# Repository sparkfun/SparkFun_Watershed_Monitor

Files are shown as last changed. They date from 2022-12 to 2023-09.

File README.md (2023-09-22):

# SparkFun Watershed Monitor

Repository Contents
-------------------

* **/Documentation** - Data sheets, additional product information
* **/Hardware** - Eagle design files (.brd, .sch)
* **/Production** - Production panel files (.brd)

License Information
-------------------

This product is _**open source**_! 

Please review the LICENSE.md file for license information. 

If you have any questions or concerns on licensing, please contact technical support on our [SparkFun forums](https://forum.sparkfun.com/viewforum.php?f=152).

Distributed as-is; no warranty is given.

- Your friends at SparkFun.

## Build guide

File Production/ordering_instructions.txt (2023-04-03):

panel size, 142x237mm
PCB thickness, 1.6mm
number of layers, 2
soldermask color, Red
silkscreen color, White
oz copper, 1oz
finish, HASL lead free
stencils, top
pcs per panel, 6
min trace width, 0.2286mm / 0.0090in
min drill size, 0.3048mm / 0.0120in

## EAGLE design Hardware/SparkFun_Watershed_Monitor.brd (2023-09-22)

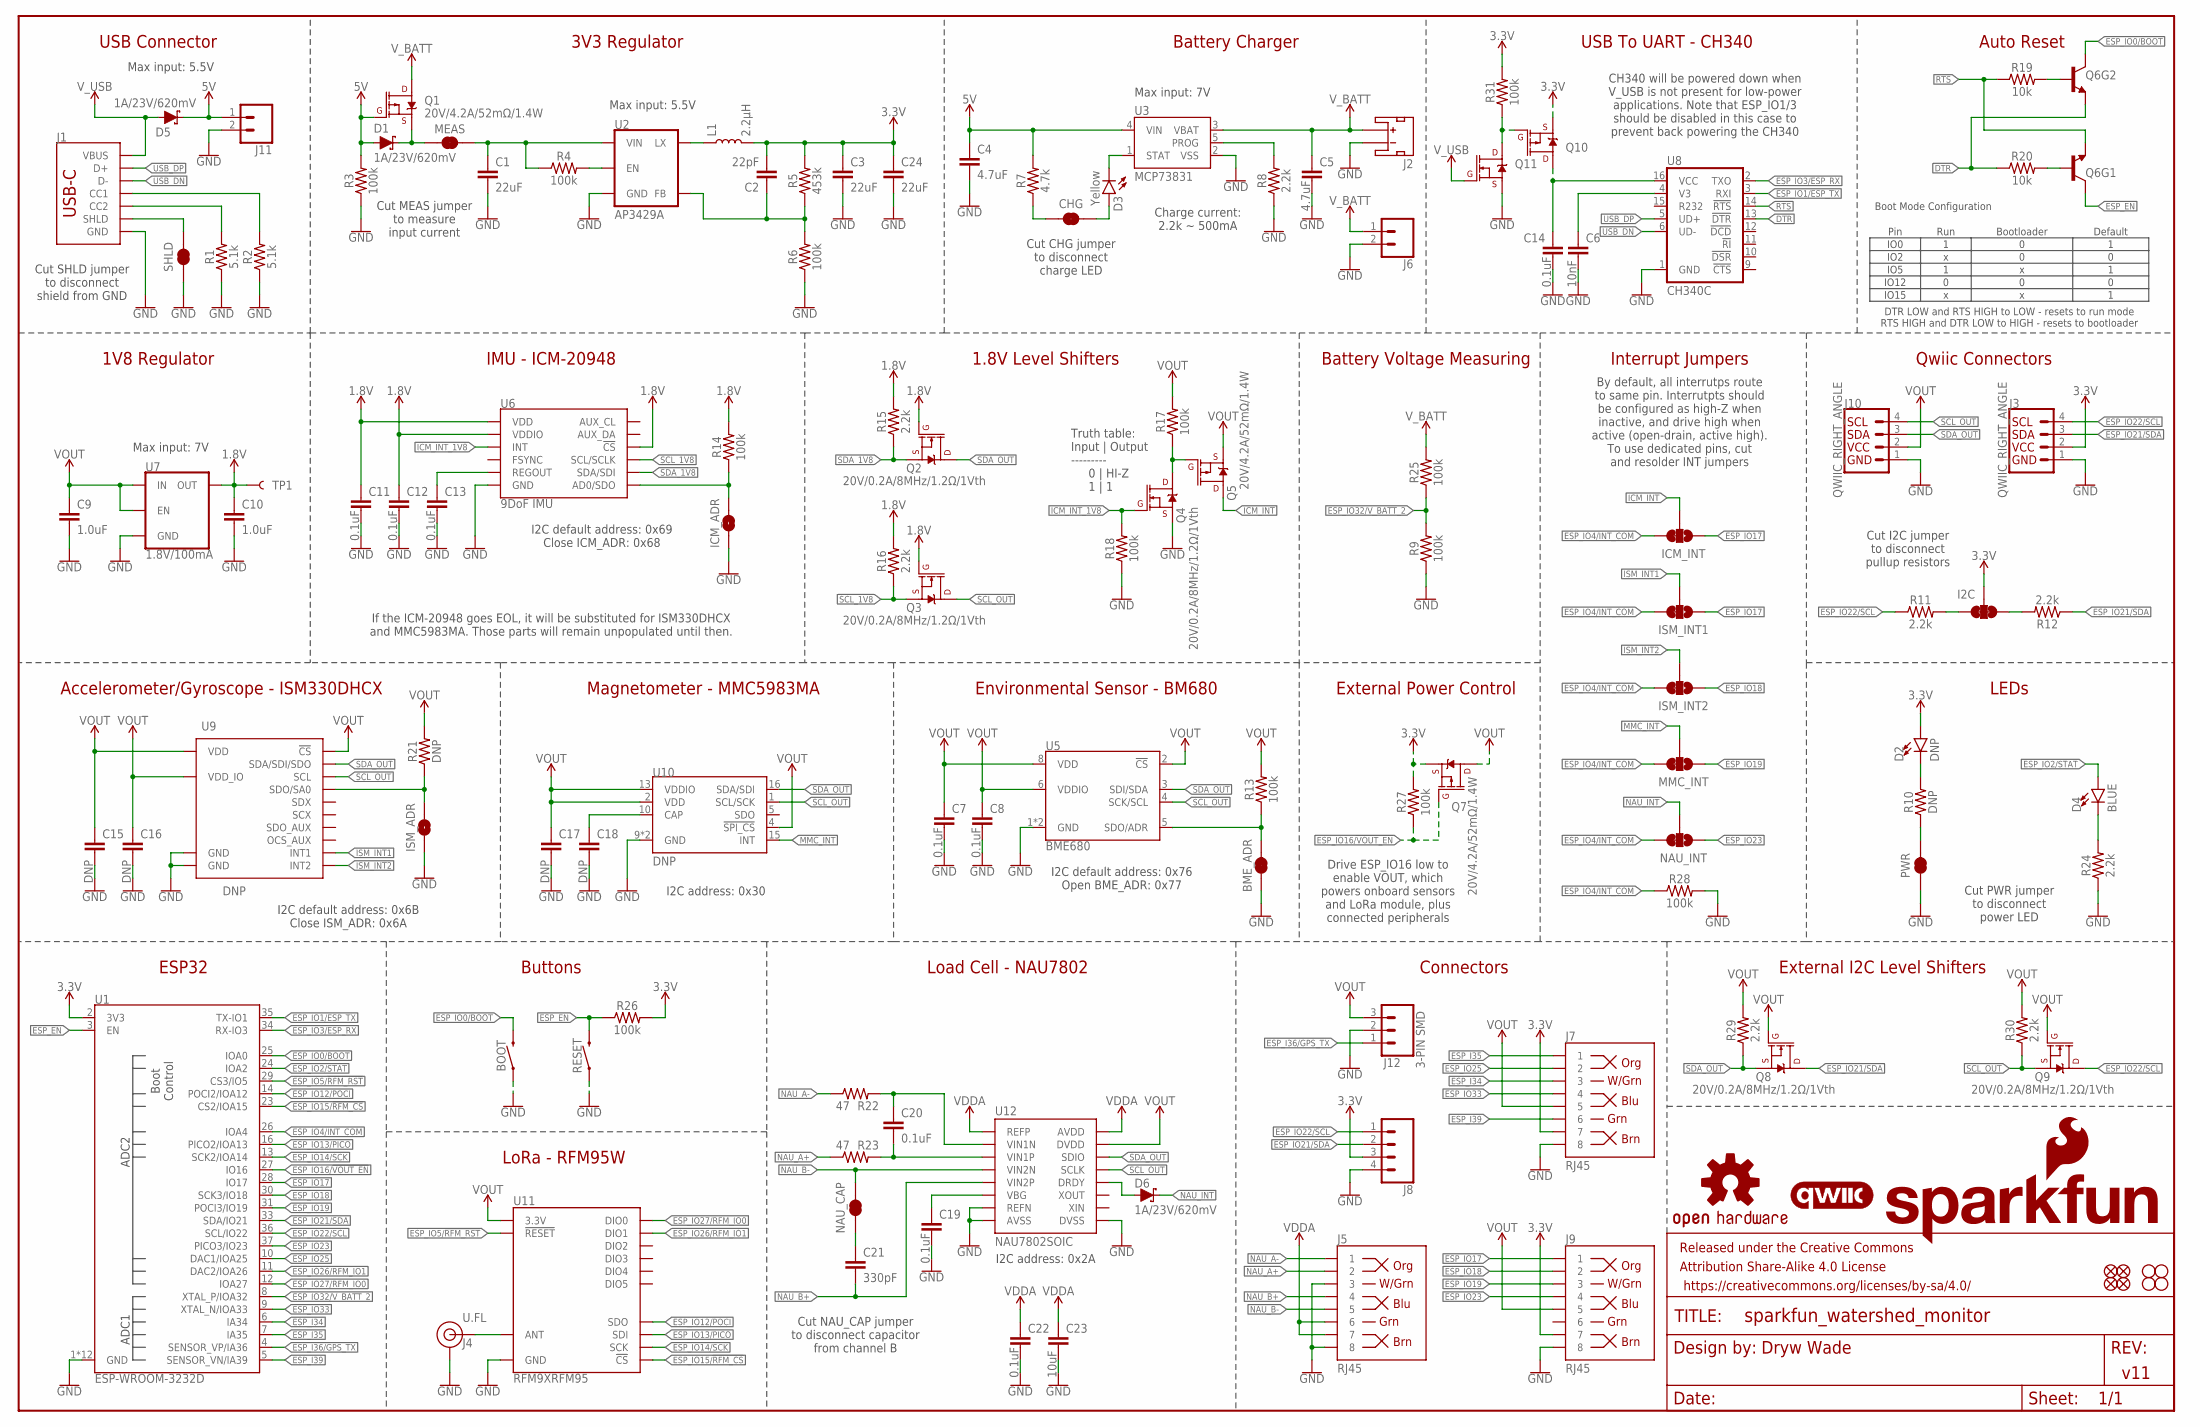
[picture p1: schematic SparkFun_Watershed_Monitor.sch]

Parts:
BME_ADR: JUMPER-SMT_2_NC_TRACE_SILK; SMT-JUMPER_2_NC_TRACE_SILK
BOOT: MOMENTARY-SWITCH-SPST-SMD-4.6X2.8MM; TACTILE_SWITCH_SMD_4.6X2.8MM
C1, C3, C24: 22uF; 0805
C2: 22pF; 0603
C4, C5: 4.7uF; 0603
C6: 10nF; 0603
C7, C8, C11, C12, C13, C14, C19, C20, C22: 0.1uF; 0603
C9, C10: 1.0uF; 0603
C15, C16, C17, C18: DNP; 0603
C21: 330pF; 0603
C23: 10uF; 0603
CHG: JUMPER-SMT_2_NC_TRACE_SILK; SMT-JUMPER_2_NC_TRACE_SILK
D1, D5, D6: 1A/23V/620mV; SOD-323
D2: DNP; LED-0603
D3: Yellow; LED-0603
D4: BLUE; LED-0603
FD1, FD2, FD3, FD4: FIDUCIAL1X2; FIDUCIAL-1X2
FRAME1: FRAME-LEDGER; CREATIVE_COMMONS
H1, H2, H3, H4: STAND-OFF
I2C: JUMPER-SMT_3_2-NC_TRACE_SILK; SMT-JUMPER_3_2-NC_TRACE_SILK
ICM_ADR: JUMPER-SMT_2_NO_SILK; SMT-JUMPER_2_NO_SILK
ICM_INT: JUMPER-SMT_3_1-NC_TRACE_SILK; SMT-JUMPER_3_1-NC_TRACE_SILK
ISM_ADR: JUMPER-SMT_2_NO_SILK; SMT-JUMPER_2_NO_SILK
ISM_INT1, ISM_INT2: JUMPER-SMT_3_1-NC_TRACE_SILK; SMT-JUMPER_3_1-NC_TRACE_SILK
J1: USB_C_2-LAYER_PADS; USB-C-16P-2LAYER-PADS
J2: JST_2MM_MALE; JST-2-SMD
J3, J10: QWIIC_RIGHT_ANGLE; JST04_1MM_RA
J4: U.FL
J5, J7, J9: RJ45; RJ45-8
J6, J11: CONN_021X02_NO_SILK; 1X02_NO_SILK
J8: CONN_041X04_NO_SILK_NO_POP; 1X04_NO_SILK
J12: 3-PIN SMD; JST-3-SMD
L1: 2.2μH; INDUCTOR_4X4MM
LOGO1: SFE_LOGO_NAME_FLAME.1_INCH; SFE_LOGO_NAME_FLAME_.1
LOGO2: OSHW-LOGOS; OSHW-LOGO-S
LOGO3: QWIIC_LOGO_4MM; QWIIC_4MM
MEAS: JUMPER-COMBO_2_NC_TRACE; COMBO-JUMPER_2_NC_TRACE
MMC_INT: JUMPER-SMT_3_1-NC_TRACE_SILK; SMT-JUMPER_3_1-NC_TRACE_SILK
NAU_CAP: JUMPER-SMT_2_NC_TRACE_SILK; SMT-JUMPER_2_NC_TRACE_SILK
NAU_INT: JUMPER-SMT_3_1-NC_TRACE_SILK; SMT-JUMPER_3_1-NC_TRACE_SILK
PWR: JUMPER-SMT_2_NC_TRACE_SILK; SMT-JUMPER_2_NC_TRACE_SILK
Q1, Q5, Q7, Q10: 20V/4.2A/52mΩ/1.4W; SOT23-3
Q2, Q3, Q4, Q8, Q9, Q11: 20V/0.2A/8MHz/1.2Ω/1Vth; SOT-416FL
Q6: TRANS_NPN_DUAL-MBT3904DW1T1; SC70-6
R1, R2: 5.1k; 0603
R3, R4, R6, R9, R13, R14, R17, R18, R25, R26, R27, R28, R31: 100k; 0603
R5: 453k; 0603
R7: 4.7k; 0603
R8, R11, R12, R15, R16, R24, R29, R30: 2.2k; 0603
R10, R21: DNP; 0603
R19, R20: 10k; 0603
R22, R23: 47; 0603
RESET: MOMENTARY-SWITCH-SPST-SMD-4.6X2.8MM; TACTILE_SWITCH_SMD_4.6X2.8MM
SHLD: JUMPER-SMT_2_NC_TRACE_SILK; SMT-JUMPER_2_NC_TRACE_SILK
TP1: TEST-POINT3X4; PAD.03X.04
U1: ESP-WROOM-3232D; ESP-WROOM-32D
U2: AP3429A; SOT23-5
U3: MCP73831; SOT23-5
U5: BME680; LGA3.0X3.0
U6: 9DoF IMU; QFN24-3X3-ICM-20948
U7: 1.8V/100mA; SC70
U8: CH340C; SO016
U9: DNP; LGA-14L
U10: DNP; LGA-16-3X3MM-4X4PINS
U11: RFM9XRFM95; RFM95
U12: NAU7802SOIC; SO16

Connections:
1.8V: C10.1, C11.1, C12.1, Q2.1 (G), Q3.1 (G), R14.2, R15.2, R16.2, TP1.1, U6.8 (VDDIO), U6.13 (VDD), U6.22 (!CS), U7.5 (OUT)
3.3V: C2.2, C3.1, C24.1, D2.A, I2C.2, J3.2, J7.7, J8.3, J9.7, L1.P$2 (2), Q7.2 (S), Q10.2 (S), R5.2, R26.2, R27.2, R31.2, U1.2 (3V3)
3V3_EN: R4.2, U2.1 (EN)
5V: C4.1, D1.A, D5.C, J11.1, Q1.1 (G), R3.2, R7.2, U3.4 (VIN)
DTR: Q6.1 (E), R20.1, U8.13 (!DTR)
ESP_EN: Q6.3 (C), R26.1, RESET.3 (2), RESET.4 (2), U1.3 (EN)
ESP_I34: J7.3, U1.6 (IA34)
ESP_I35: J7.1, U1.7 (IA35)
ESP_I36/GPS_TX: J12.1 (3), U1.4 (SENSOR_VP/IA36)
ESP_I39: J7.6, U1.5 (SENSOR_VN/IA39)
ESP_IO0/BOOT: BOOT.3 (2), BOOT.4 (2), Q6.6 (C), U1.25 (IOA0)
ESP_IO1/ESP_TX: U1.35 (TX-IO1), U8.3 (RXI)
ESP_IO2/STAT: D4.A, U1.24 (IOA2)
ESP_IO3/ESP_RX: U1.34 (RX-IO3), U8.2 (TXO)
ESP_IO4/INT_COM: ICM_INT.3, ISM_INT1.3, ISM_INT2.3, MMC_INT.3, NAU_INT.3, R28.1, U1.26 (IOA4)
ESP_IO5/!RFM_RST!: U1.29 (CS3/IO5), U11.!RESET
ESP_IO12/POCI: U1.14 (POCI2/IOA12), U11.SDO
ESP_IO13/PICO: U1.16 (PICO2/IOA13), U11.SDI
ESP_IO14/SCK: U1.13 (SCK2/IOA14), U11.SCK
ESP_IO15/!RFM_CS!: U1.23 (CS2/IOA15), U11.NSS (!CS!)
ESP_IO16/!VOUT_EN!: Q7.1 (G), R27.1, U1.27 (IO16)
ESP_IO17: ICM_INT.1, ISM_INT1.1, J9.1, U1.28 (IO17)
ESP_IO18: ISM_INT2.1, J9.2, U1.30 (SCK3/IO18)
ESP_IO19: J9.3, MMC_INT.1, U1.31 (POCI3/IO19)
ESP_IO21/SDA: J3.3, J8.2, Q8.3 (D), R12.1, U1.33 (SDA/IO21)
ESP_IO22/SCL: J3.4, J8.1, Q9.3 (D), R11.1, U1.36 (SCL/IO22)
ESP_IO23: J9.4, NAU_INT.1, U1.37 (PICO3/IO23)
ESP_IO25: J7.2, U1.10 (DAC1/IOA25)
ESP_IO26/RFM_IO1: U1.11 (DAC2/IOA26), U11.DIO1
ESP_IO27/RFM_IO0: U1.12 (IOA27), U11.DIO0
ESP_IO32/V_BATT_2: R9.2, R25.1, U1.8 (XTAL_P/IOA32)
ESP_IO33: J7.4, U1.9 (XTAL_N/IOA33)
GND: BME_ADR.1, BOOT.1, BOOT.2 (1), C1.2, C3.2, C4.2, C5.2, C6.2, C7.2, C8.2, C9.2, C10.2, C11.2, C12.2, C13.2, C14.2, C15.2, C16.2, C17.2, C18.2, C19.2, C22.2, C23.2, C24.2, ICM_ADR.1, ISM_ADR.1, J1.GND, J1.GND2 (GND), J2.1 (-), J3.1, J4.1 (GND), J4.2 (GND), J5.3, J5.8, J6.2, J7.8, J8.4, J9.8, J10.1, J11.2, J12.2, PWR.1, Q4.2 (S), Q11.2 (S), R1.1, R2.1, R3.1, R6.1, R8.1, R9.1, R18.1, R24.1, R28.2, RESET.1, RESET.2 (1), SHLD.1, U1.1 (GND), U1.15 (GND), U1.38 (GND), U1.GND, U1.GNDT1 (GND), U1.GNDT2 (GND), U1.GNDT3 (GND), U1.GNDT4 (GND), U1.GNDT5 (GND), U1.GNDT6 (GND), U1.GNDT7 (GND), U1.GNDT8 (GND), U2.2 (GND), U3.2 (VSS), U5.1 (GND), U5.7 (GND), U6.18 (GND), U6.20 (GND), U7.2 (GND), U8.1 (GND), U9.P6 (GND), U9.P7 (GND), U10.9 (GND), U10.11 (GND), U11.GND@1 (GND), U11.GND@2 (GND), U11.GND@3 (GND), U12.7 (REFN), U12.8 (AVSS), U12.9 (DVSS)
ICM_INT: ICM_INT.2, Q5.3 (D)
ICM_INT_1V8: Q4.1 (G), R18.2, U6.12 (INT)
ISM_INT1: ISM_INT1.2, U9.P4 (INT1)
ISM_INT2: ISM_INT2.2, U9.P9 (INT2)
MMC_INT: MMC_INT.2, U10.15 (INT)
unnamed: D4.C, R24.2
unnamed: L1.P$1 (1), U2.3 (LX)
unnamed: C1.1, MEAS.2, MEAS.4 (2), R4.1, U2.4 (VIN)
unnamed: J1.B5 (CC2), R1.2
unnamed: J1.A5 (CC1), R2.2
unnamed: D1.C, MEAS.1, MEAS.3 (1), Q1.2 (S)
unnamed: C2.1, R5.1, R6.2, U2.5 (FB)
unnamed: D3.C, U3.1 (STAT)
unnamed: CHG.2, D3.A
unnamed: CHG.1, R7.1
unnamed: R8.2, U3.5 (PROG)
unnamed: C6.1, U8.4 (V3)
unnamed: BME_ADR.2, R13.1, U5.5 (SDO/ADR)
unnamed: C13.1, U6.10 (REGOUT)
unnamed: I2C.1, R12.2
unnamed: I2C.3, R11.2
unnamed: ICM_ADR.2, R14.1, U6.9 (AD0/SDO)
unnamed: Q6.5 (B), R20.2
unnamed: Q6.2 (B), R19.2
unnamed: C18.1, U10.10 (CAP)
unnamed: ISM_ADR.2, R21.1, U9.P1 (SDO/SA0)
unnamed: C19.1, U12.6 (VBG)
unnamed: D2.C, R10.2
unnamed: C21.1, NAU_CAP.1
unnamed: J4.FEED (SIGNAL), U11.ANT
unnamed: PWR.2, R10.1
unnamed: C20.2, R23.2, U12.3 (VIN1P)
unnamed: C20.1, R22.2, U12.2 (VIN1N)
unnamed: D6.A, U12.12 (DRDY)
unnamed: Q4.3 (D), Q5.1 (G), R17.1
unnamed: Q10.1 (G), Q11.3 (D), R31.1
unnamed: C14.1, Q10.3 (D), U8.16 (VCC)
NAU_A+: J5.2, R23.1
NAU_A-: J5.1, R22.1
NAU_B+: C21.2, J5.4, U12.5 (VIN2P)
NAU_B-: J5.5, NAU_CAP.2, U12.4 (VIN2N)
NAU_INT: D6.C, NAU_INT.2
RTS: Q6.4 (E), R19.1, U8.14 (!RTS)
SCL_1V8: Q3.2 (S), R16.1, U6.23 (SCL/SCLK)
SCL_OUT: J10.4, Q3.3 (D), Q9.2 (S), R30.1, U5.4 (SCK/SCL), U9.P13 (SCL), U10.1 (SCL/SCK), U12.13 (SCLK)
SDA_1V8: Q2.2 (S), R15.1, U6.24 (SDA/SDI)
SDA_OUT: J10.3, Q2.3 (D), Q8.2 (S), R29.1, U5.3 (SDI/SDA), U9.P14 (SDA/SDI/SDO), U10.16 (SDA/SDI), U12.14 (SDIO)
SHLD: J1.SHLD1 (SHLD), J1.SHLD2 (SHLD), J1.SHLD3 (SHLD), J1.SHLD4 (SHLD), SHLD.2
USB_DN: J1.A7 (D-), J1.B7 (D-), U8.6 (UD-)
USB_DP: J1.A6 (D+), J1.B6 (D+), U8.5 (UD+)
VDDA: C22.1, C23.1, J5.6, J5.7, U12.1 (REFP), U12.16 (AVDD)
VOUT: C7.1, C8.1, C9.1, C15.1, C16.1, C17.1, J7.5, J9.5, J10.2, J12.3 (1), Q5.2 (S), Q7.3 (D), Q8.1 (G), Q9.1 (G), R13.2, R17.2, R21.2, R29.2, R30.2, U5.2 (!CS), U5.6 (VDDIO), U5.8 (VDD), U7.1 (IN), U7.3 (EN), U9.P5 (VDD_IO), U9.P8 (VDD), U9.P12 (!CS!), U10.2 (VDD), U10.4 (!SPI_CS!), U10.13 (VDDIO), U11.3.3V, U12.15 (DVDD)
V_BATT: C5.1, J2.2 (+), J6.1, Q1.3 (D), R25.2, U3.3 (VBAT)
V_USB: D5.A, J1.VBUS1 (VBUS), J1.VBUS2 (VBUS), Q11.1 (G)

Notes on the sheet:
Dryw Wade
v11
USB Connector
3V3 Regulator
Battery Charger
LEDs
Qwiic Connectors
Environmental Sensor - BM680
1V8 Regulator
IMU - ICM-20948
1.8V Level Shifters
Cut SHLD jumper to disconnect shield from GND
Cut MEAS jumper to measure input current
Cut CHG jumper to disconnect charge LED
Charge current: 2.2k ~ 500mA
Cut PWR jumper to disconnect power LED
Cut I2C jumper to disconnect pullup resistors
I2C default address: 0x69 Close ICM_ADR: 0x68
By default, all interrutps route to same pin. Interrutpts should be configured as high-Z when inactive, and drive high when active (open-drain, active high). To use dedicated pins, cut and resolder INT jumpers
Interrupt Jumpers
USB To UART - CH340
Accelerometer/Gyroscope - ISM330DHCX
Magnetometer - MMC5983MA
LoRa - RFM95W
Load Cell - NAU7802
ESP32
Cut NAU_CAP jumper to disconnect capacitor from channel B
Buttons
Auto Reset
Connectors
Battery Voltage Measuring
Max input: 5.5V
If the ICM-20948 goes EOL, it will be substituted for ISM330DHCX and MMC5983MA. Those parts will remain unpopulated until then.
I2C default address: 0x6B Close ISM_ADR: 0x6A
I2C default address: 0x76 Open BME_ADR: 0x77
I2C address: 0x2A
Max input: 7V
DTR LOW and RTS HIGH to LOW - resets to run mode RTS HIGH and DTR LOW to HIGH - resets to bootloader
Pin
IO0

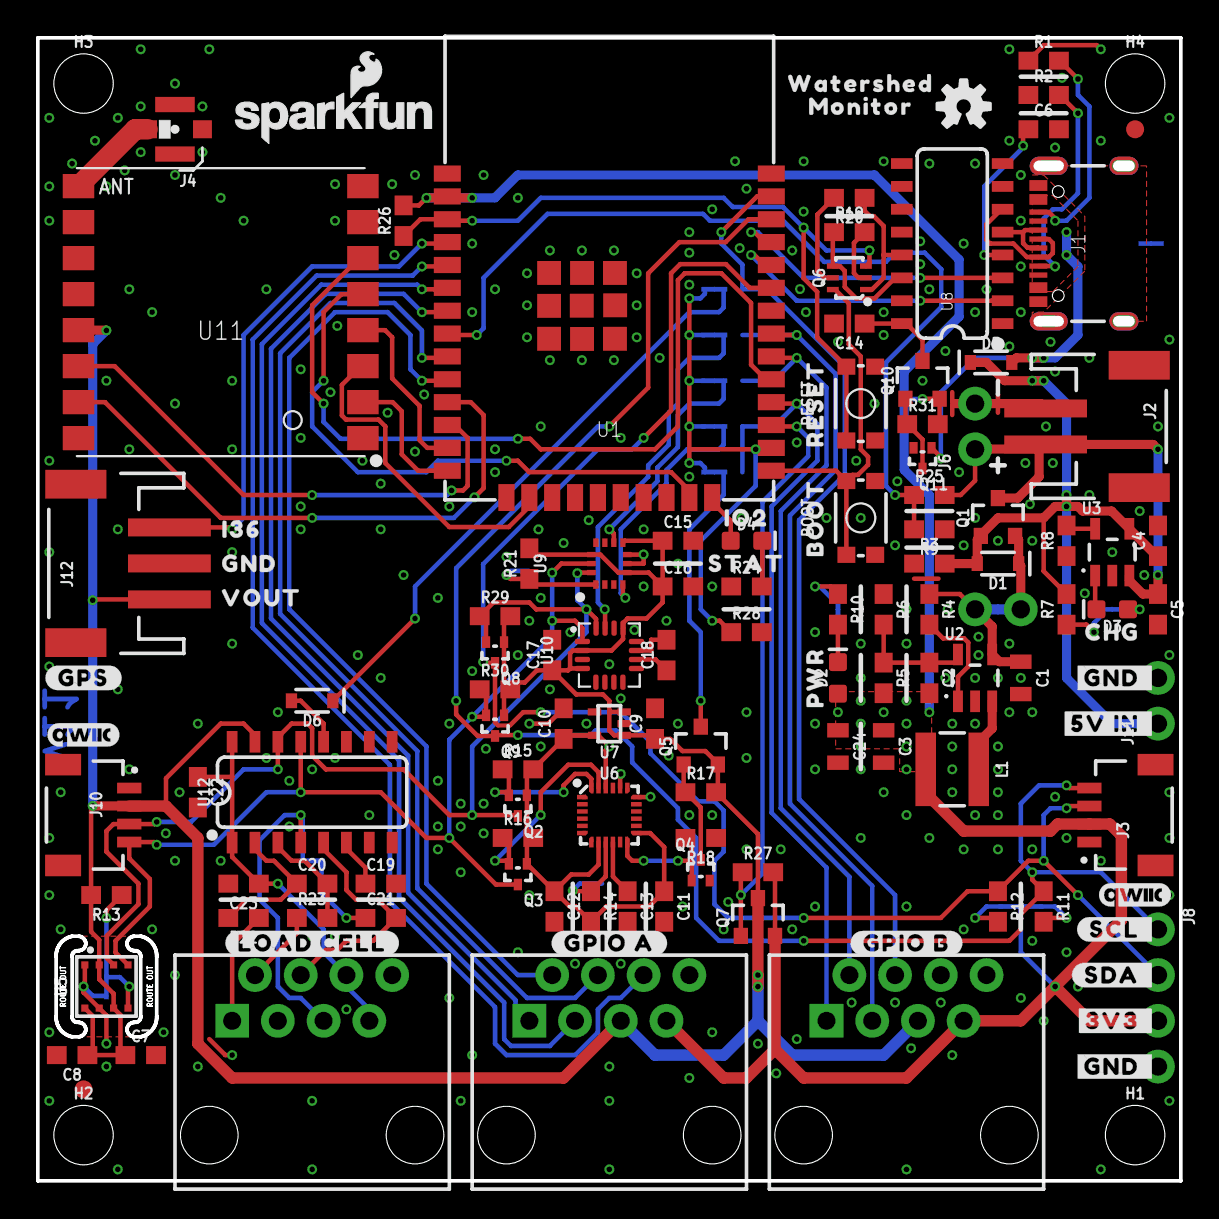
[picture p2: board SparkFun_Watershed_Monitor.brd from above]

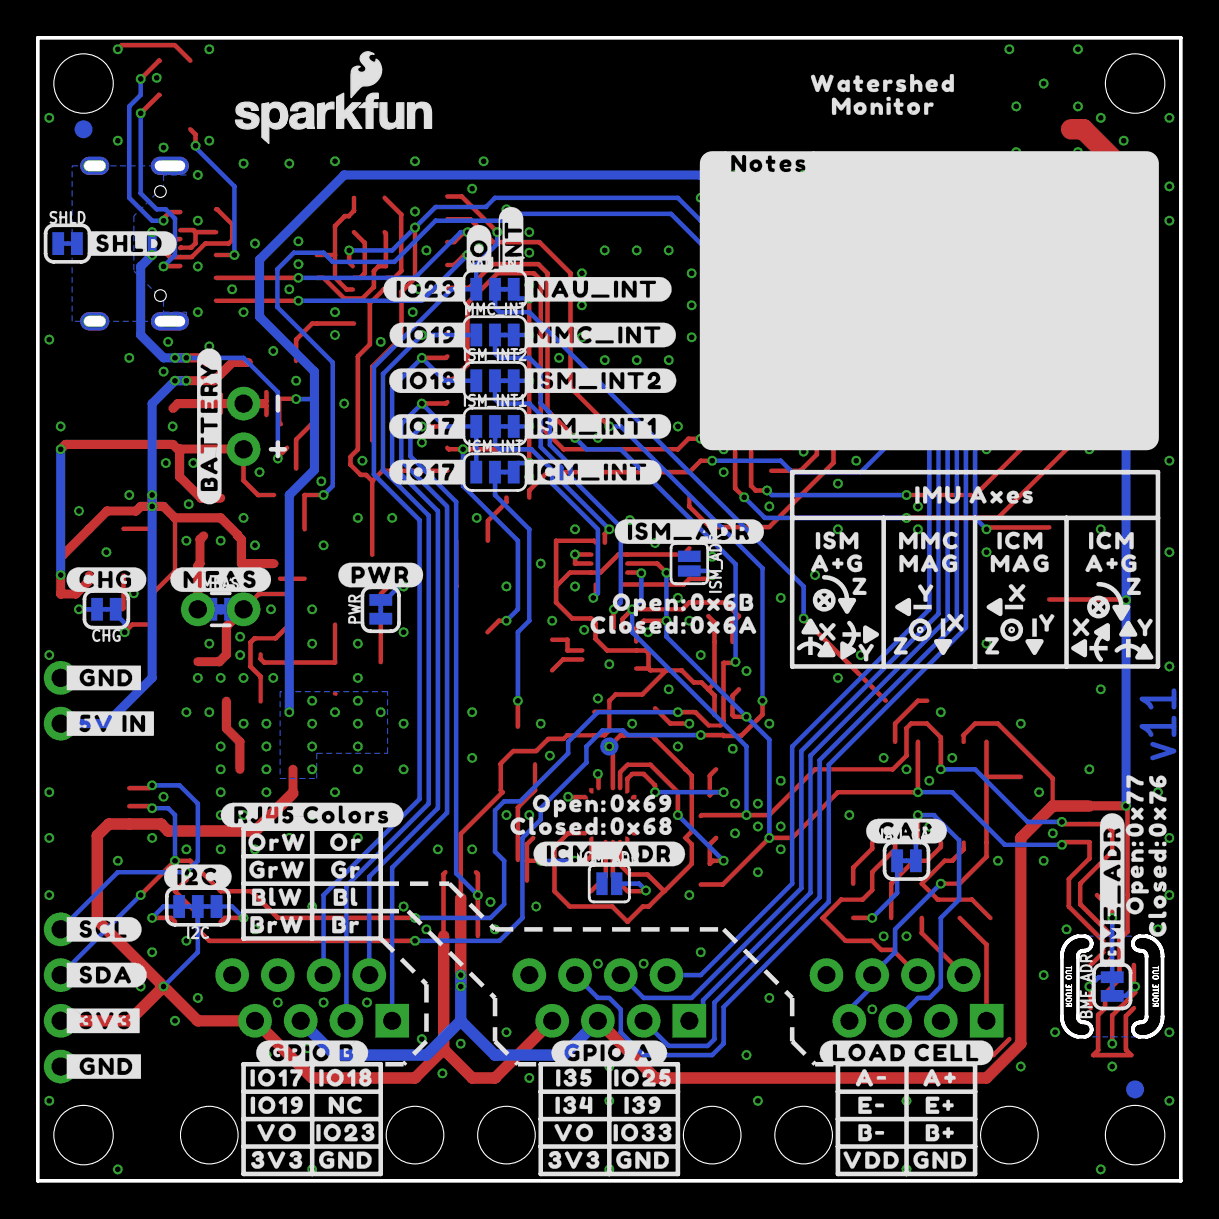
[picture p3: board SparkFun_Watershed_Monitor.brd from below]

Board: 2 copper layers, 63.5 x 63.5 mm, 249 parts (118 on the bottom side), 87 nets.

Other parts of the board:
LOGO4: QWIIC_LOGO_4MM; QWIIC_4MM
LOGO5: SFE_LOGO_NAME_FLAME.1_INCH; SFE_LOGO_NAME_FLAME_.1
U$2, U$115: WATERSHED0
U$3, U$116: MONITOR0
U$4, U$8, U$11: GND0
U$5, U$67: #IO17#0
U$6, U$79: #GND_#0
U$7, U$80: #_GND#0
U$9: #MEAS#0
U$10, U$24: 3V30
U$12: A#0
U$13: VDD0
U$14: #CHG#0
U$15: #I2C#0
U$16: CHG0
U$17: #CAP#0
U$18: #BME_ADR#0
U$19: #ICM_ADR#0
U$20: #ISM_ADR#0
U$21: #BATTERY#0
U$22: #SHLD#0
U$23: I360
U$25, U$69: VO0
U$26: VOUT0
U$27: RESET0
U$28: BOOT0
U$29: PWR0
U$30: STAT0
U$31: IO20
U$32: ORW0
U$33: OR0
U$34: GRW0
U$35: GR0
U$36: BLW0
U$37: BL0
U$38: BRW0
U$39: BR0
U$40: A#1
U$41: B#0
U$42: B#1
U$43: E#0
U$44: E#1
U$45: #RJ45_COLORS#0
U$46: #PWR#0
U$47: #3V3_#0
U$48: #SDA_#0
U$49: ORDERING_INSTRUCTIONS
U$50, U$55: #LOAD_CELL#0
U$51, U$86: #GPIO_A#0
U$52: IO250
U$53, U$87: #GPIO_B#0
U$54: IO330
U$56: #SCL_#0
U$57: NC0
U$58: IO170
U$59: IO180
U$60: IO190
U$61: I340
U$62: I350
U$64: I390
U$65: #IO19#0
U$66: #IO18#0
U$68: #IO23#0
U$70: #NAU_INT#0
U$71: #MMC_INT#0
U$72: #ISM_INT2#0
U$73: #ISM_INT1#0
U$74: #ICM_INT#0
U$75: #IO#0
U$76: ##INT##0
U$77: #NOTES#0
U$78: IO230
U$81: #_SCL#1
U$82, U$121, U$125: OPEN#0
U$83, U$122, U$126: CLOSED#0
U$84: #_SDA#2
U$85: #_3V3#0
U$88: #GPS#0
U$89: GND3
U$94, U$100, U$104, U$138: X0
U$95, U$102, U$105, U$139: Y0
U$96, U$103, U$106, U$140: Z0
U$110, U$137: ICM0
U$111: ISM0
U$112: MMC0
U$113: IMU_AXES0
U$117: #5V_IN_#0
U$118: #_5V_IN#0
U$119: 0X770
U$120: 0X760
U$123: 0X6A0
U$124: 0X6B0
U$127: 0X690
U$128: 0X680
U$141, U$142: MAG0
U$143, U$144: A#G0

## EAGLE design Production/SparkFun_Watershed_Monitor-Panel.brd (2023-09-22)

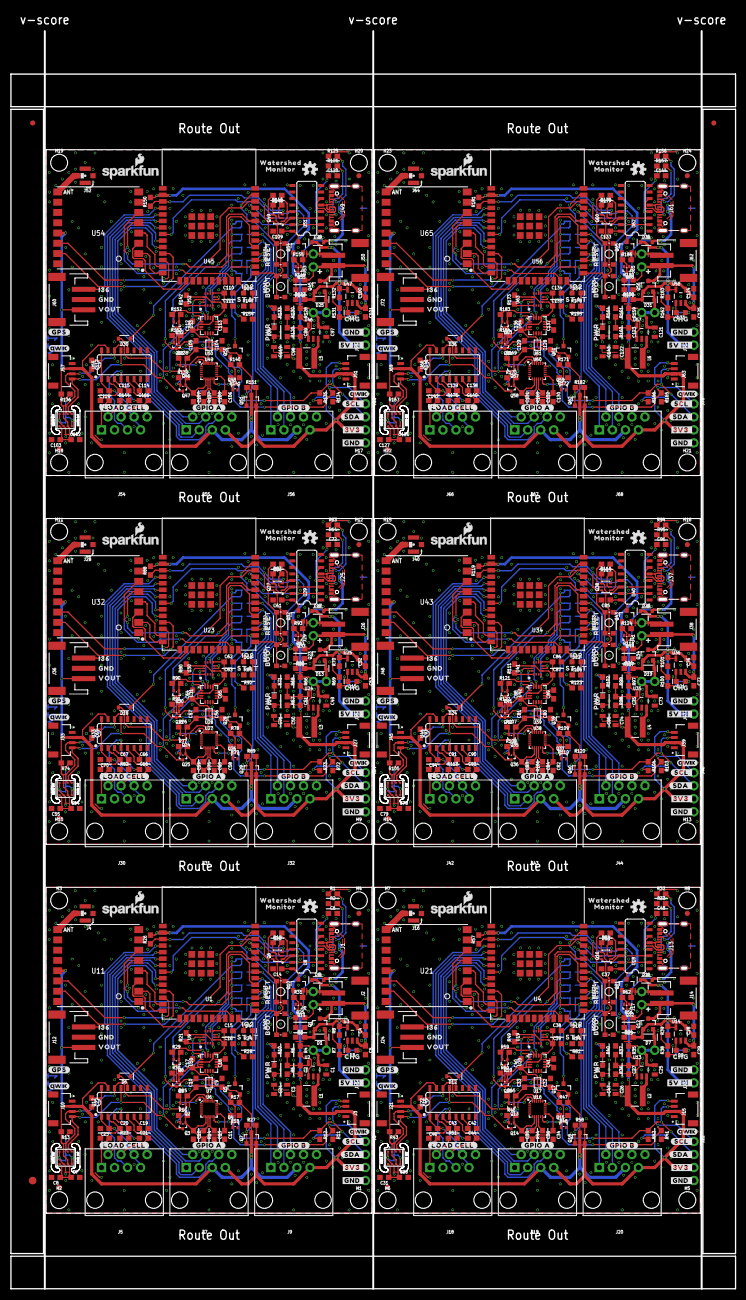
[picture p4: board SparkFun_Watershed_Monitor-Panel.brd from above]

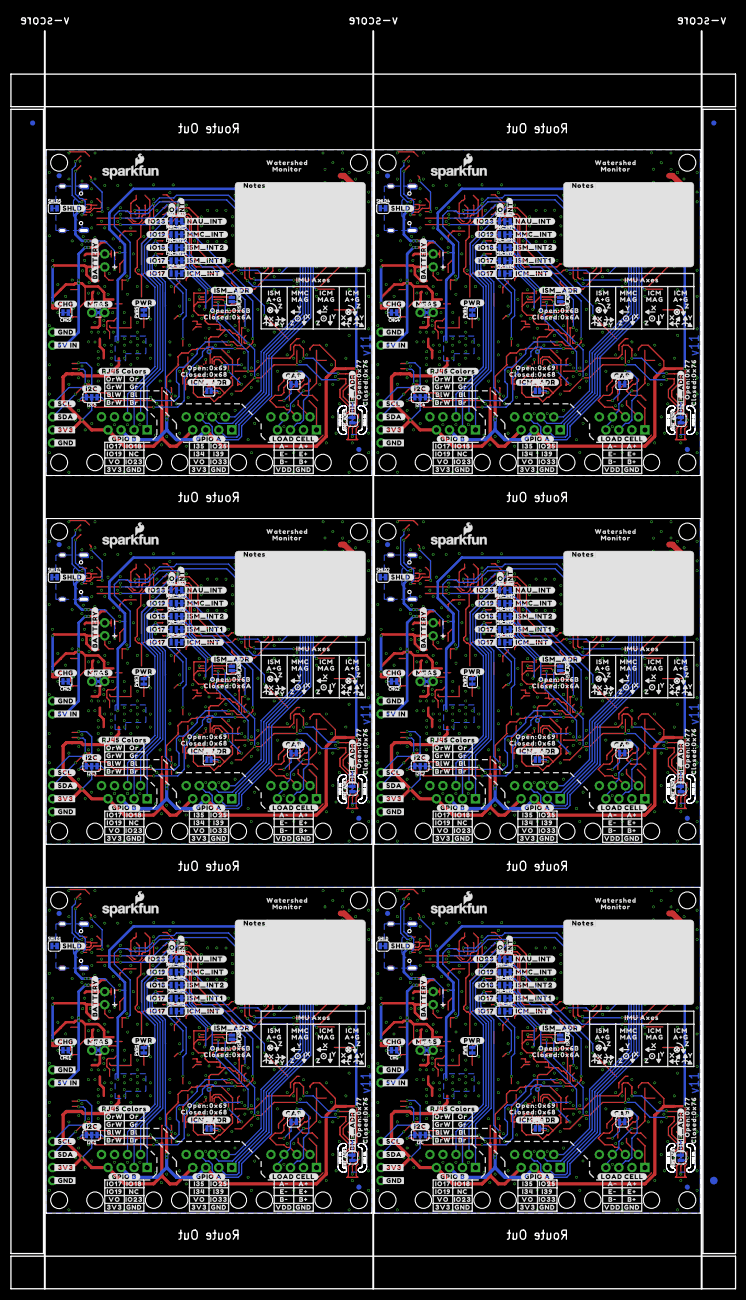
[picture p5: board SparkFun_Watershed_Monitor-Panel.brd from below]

Board: 2 copper layers, 141.2 x 245.1 mm, 1488 parts (711 on the bottom side), 522 nets.

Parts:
BME_ADR, BME_ADR1, BME_ADR2, BME_ADR3, BME_ADR4, BME_ADR5: JUMPER-SMT_2_NC_TRACE_SILK; SMT-JUMPER_2_NC_TRACE_SILK
BOOT, BOOT1, BOOT2, BOOT3, BOOT4, BOOT5: MOMENTARY-SWITCH-SPST-SMD-4.6X2.8MM; TACTILE_SWITCH_SMD_4.6X2.8MM
C1, C3, C24, C25, C26, C47, C49, C50, C71, C73, C74, C95, C97, C98, C119, C121, C122, C143: 22uF; 0805
C2, C27, C51, C75, C99, C123: 22pF; 0603
C4, C5, C28, C29, C52, C53, C76, C77, C100, C101, C124, C125: 4.7uF; 0603
C6, C48, C72, C96, C120, C144: 10nF; 0603
C7, C8, C11, C12, C13, C14, C19, C20, C22, C30, C31, C34, C35, C36, C37, C42, C43, C45, C54, C55, C58, C59, C60, C61, C66, C67, C69, C78, C79, C82, C83, C84, C85, C90, C91, C93, C102, C103, C106, C107, C108, C109, C114, C115, C117, C126, C127, C130, C131, C132, C133, C138, C139, C141: 0.1uF; 0603
C9, C10, C32, C33, C56, C57, C80, C81, C104, C105, C128, C129: 1.0uF; 0603
C15, C16, C17, C18, C38, C39, C40, C41, C62, C63, C64, C65, C86, C87, C88, C89, C110, C111, C112, C113, C134, C135, C136, C137: DNP; 0603
C21, C44, C68, C92, C116, C140: 330pF; 0603
C23, C46, C70, C94, C118, C142: 10uF; 0603
CHG, CHG1, CHG2, CHG3, CHG4, CHG5: JUMPER-SMT_2_NC_TRACE_SILK; SMT-JUMPER_2_NC_TRACE_SILK
D1, D5, D6, D7, D11, D12, D13, D17, D18, D19, D23, D24, D25, D29, D30, D31, D35, D36: 1A/23V/620mV; SOD-323
D2, D8, D14, D20, D26, D32: DNP; LED-0603
D3, D9, D15, D21, D27, D33: Yellow; LED-0603
D4, D10, D16, D22, D28, D34: BLUE; LED-0603
E$1, E$2, E$3, E$4: FIDUCIAL-1X2
E$5, E$6: FIDUCIAL-1.5X3
FD1, FD2, FD3, FD4, FD5, FD6, FD7, FD8, FD9, FD10, FD11, FD12, FD13, FD14, FD15, FD16, FD17, FD18, FD19, FD20, FD21, FD22, FD23, FD24: FIDUCIAL1X2; FIDUCIAL-1X2
H1, H2, H3, H4, H5, H6, H7, H8, H9, H10, H11, H12, H13, H14, H15, H16, H17, H18, H19, H20, H21, H22, H23, H24: STAND-OFF
I2C, I2C1, I2C2, I2C3, I2C4, I2C5: JUMPER-SMT_3_2-NC_TRACE_SILK; SMT-JUMPER_3_2-NC_TRACE_SILK
ICM_ADR, ICM_ADR1, ICM_ADR2, ICM_ADR3, ICM_ADR4, ICM_ADR5: JUMPER-SMT_2_NO_SILK; SMT-JUMPER_2_NO_SILK
ICM_INT, ICM_INT1, ICM_INT2, ICM_INT3, ICM_INT4, ICM_INT5: JUMPER-SMT_3_1-NC_TRACE_SILK; SMT-JUMPER_3_1-NC_TRACE_SILK
ISM_ADR, ISM_ADR1, ISM_ADR2, ISM_ADR3, ISM_ADR4, ISM_ADR5: JUMPER-SMT_2_NO_SILK; SMT-JUMPER_2_NO_SILK
ISM_INT1, ISM_INT2, ISM_INT3, ISM_INT4, ISM_INT5, ISM_INT6, ISM_INT7, ISM_INT8, ISM_INT9, ISM_INT10, ISM_INT11, ISM_INT12: JUMPER-SMT_3_1-NC_TRACE_SILK; SMT-JUMPER_3_1-NC_TRACE_SILK
J1, J13, J25, J37, J49, J61: USB-C-16P-2LAYER-PADS
J2, J14, J26, J38, J50, J62: JST-2-SMD
J3, J10, J15, J21, J27, J33, J39, J45, J51, J57, J63, J69: QWIIC_RIGHT_ANGLE; JST04_1MM_RA
J4, J16, J28, J40, J52, J64: U.FL
J5, J7, J9, J18, J19, J20, J30, J31, J32, J42, J43, J44, J54, J55, J56, J66, J67, J68: RJ45; RJ45-8
J6, J11, J17, J23, J29, J35, J41, J47, J53, J59, J65, J71: 1X02_NO_SILK
J8, J22, J34, J46, J58, J70: 1X04_NO_SILK
J12, J24, J36, J48, J60, J72: 3-PIN SMD; JST-3-SMD
L1, L2, L3, L4, L5, L6: 2.2μH; INDUCTOR_4X4MM
LOGO1, LOGO5, LOGO6, LOGO10, LOGO11, LOGO15, LOGO16, LOGO20, LOGO21, LOGO25, LOGO26, LOGO30: SFE_LOGO_NAME_FLAME.1_INCH; SFE_LOGO_NAME_FLAME_.1
LOGO2, LOGO7, LOGO12, LOGO17, LOGO22, LOGO27: OSHW-LOGOS; OSHW-LOGO-S
LOGO3, LOGO4, LOGO8, LOGO9, LOGO13, LOGO14, LOGO18, LOGO19, LOGO23, LOGO24, LOGO28, LOGO29: QWIIC_LOGO_4MM; QWIIC_4MM
MEAS, MEAS1, MEAS2, MEAS3, MEAS4, MEAS5: JUMPER-COMBO_2_NC_TRACE; COMBO-JUMPER_2_NC_TRACE
MMC_INT, MMC_INT1, MMC_INT2, MMC_INT3, MMC_INT4, MMC_INT5: JUMPER-SMT_3_1-NC_TRACE_SILK; SMT-JUMPER_3_1-NC_TRACE_SILK
NAU_CAP, NAU_CAP1, NAU_CAP2, NAU_CAP3, NAU_CAP4, NAU_CAP5: JUMPER-SMT_2_NC_TRACE_SILK; SMT-JUMPER_2_NC_TRACE_SILK
NAU_INT, NAU_INT1, NAU_INT2, NAU_INT3, NAU_INT4, NAU_INT5: JUMPER-SMT_3_1-NC_TRACE_SILK; SMT-JUMPER_3_1-NC_TRACE_SILK
PWR, PWR1, PWR2, PWR3, PWR4, PWR5: JUMPER-SMT_2_NC_TRACE_SILK; SMT-JUMPER_2_NC_TRACE_SILK
Q1, Q5, Q7, Q10, Q12, Q17, Q18, Q21, Q23, Q28, Q29, Q32, Q34, Q39, Q40, Q43, Q45, Q50, Q51, Q54, Q56, Q61, Q62, Q65: 20V/4.2A/52mΩ/1.4W; SOT23-3
Q2, Q3, Q4, Q8, Q9, Q11, Q13, Q14, Q15, Q19, Q20, Q22, Q24, Q25, Q26, Q30, Q31, Q33, Q35, Q36, Q37, Q41, Q42, Q44, Q46, Q47, Q48, Q52, Q53, Q55, Q57, Q58, Q59, Q63, Q64, Q66: 20V/0.2A/8MHz/1.2Ω/1Vth; SOT-416FL
Q6, Q16, Q27, Q38, Q49, Q60: SC70-6
R1, R2, R32, R33, R63, R64, R94, R95, R125, R126, R156, R157: 5.1k; 0603
R3, R4, R6, R9, R13, R14, R17, R18, R25, R26, R27, R28, R31, R34, R35, R37, R43, R44, R47, R48, R55, R56, R57, R58, R61, R62, R65, R66, R68, R74, R75, R78, R79, R86, R87, R88, R89, R92, R93, R96, R97, R99, R105, R106, R109, R110, R117, R118, R119, R120, R123, R124, R127, R128, R130, R136, R137, R140, R141, R148, R149, R150, R151, R154, R155, R158, R159, R161, R167, R168, R171, R172, R179, R180, R181, R182, R185, R186: 100k; 0603
R5, R36, R67, R98, R129, R160: 453k; 0603
R7, R38, R69, R100, R131, R162: 4.7k; 0603
R8, R11, R12, R15, R16, R24, R29, R30, R39, R41, R42, R45, R46, R54, R59, R60, R70, R72, R73, R76, R77, R85, R90, R91, R101, R103, R104, R107, R108, R116, R121, R122, R132, R134, R135, R138, R139, R147, R152, R153, R163, R165, R166, R169, R170, R178, R183, R184: 2.2k; 0603
R10, R21, R40, R49, R71, R80, R102, R111, R133, R142, R164, R173: DNP; 0603
R19, R20, R52, R53, R83, R84, R114, R115, R145, R146, R176, R177: 10k; 0603
R22, R23, R50, R51, R81, R82, R112, R113, R143, R144, R174, R175: 47; 0603
RESET, RESET1, RESET2, RESET3, RESET4, RESET5: MOMENTARY-SWITCH-SPST-SMD-4.6X2.8MM; TACTILE_SWITCH_SMD_4.6X2.8MM
SHLD, SHLD1, SHLD2, SHLD3, SHLD4, SHLD5: JUMPER-SMT_2_NC_TRACE_SILK; SMT-JUMPER_2_NC_TRACE_SILK
TP1, TP2, TP3, TP4, TP5, TP6: TEST-POINT3X4; PAD.03X.04
U1, U4, U23, U34, U45, U56: ESP-WROOM-3232D; ESP-WROOM-32D
U2, U13, U24, U35, U46, U57: AP3429A; SOT23-5
U3, U14, U25, U36, U47, U58: MCP73831; SOT23-5
U5, U15, U26, U37, U48, U59: BME680; LGA3.0X3.0
U6, U16, U27, U38, U49, U60: 9DoF IMU; QFN24-3X3-ICM-20948
U7, U17, U28, U39, U50, U61: 1.8V/100mA; SC70
U8, U18, U29, U40, U51, U62: CH340C; SO016
U9, U19, U30, U41, U52, U63: DNP; LGA-14L
U10, U20, U31, U42, U53, U64: DNP; LGA-16-3X3MM-4X4PINS
U11, U21, U32, U43, U54, U65: RFM9XRFM95; RFM95
U12, U22, U33, U44, U55, U66: NAU7802SOIC; SO16
U$1, U$2, U$115, U$196, U$243, U$317, U$364, U$438, U$485, U$559, U$606, U$680: WATERSHED0
U$3, U$49, U$116, U$197, U$244, U$318, U$365, U$439, U$486, U$560, U$607, U$681: MONITOR0
U$4, U$8, U$11, U$147, U$148, U$150, U$268, U$269, U$271, U$389, U$390, U$392, U$510, U$511, U$513, U$631, U$632, U$634: GND0
U$5, U$67, U$170, U$239, U$291, U$360, U$412, U$481, U$533, U$602, U$654, U$723: #IO17#0
U$6, U$79, U$180, U$182, U$301, U$303, U$422, U$424, U$543, U$545, U$664, U$666: #GND_#0
U$7, U$80, U$181, U$183, U$302, U$304, U$423, U$425, U$544, U$546, U$665, U$667: #_GND#0
U$9, U$63, U$245, U$366, U$487, U$608: #MEAS#0
U$10, U$24, U$149, U$241, U$270, U$362, U$391, U$483, U$512, U$604, U$633, U$725: 3V30
U$12, U$152, U$273, U$394, U$515, U$636: A#0
U$13, U$151, U$272, U$393, U$514, U$635: VDD0
U$14, U$90, U$246, U$367, U$488, U$609: #CHG#0
U$15, U$91, U$247, U$368, U$489, U$610: #I2C#0
U$16, U$92, U$248, U$369, U$490, U$611: CHG0
U$17, U$93, U$249, U$370, U$491, U$612: #CAP#0
U$18, U$97, U$250, U$371, U$492, U$613: #BME_ADR#0
U$19, U$98, U$251, U$372, U$493, U$614: #ICM_ADR#0
U$20, U$99, U$252, U$373, U$494, U$615: #ISM_ADR#0
U$21, U$101, U$253, U$374, U$495, U$616: #BATTERY#0
U$22, U$107, U$254, U$375, U$496, U$617: #SHLD#0
U$23, U$234, U$355, U$476, U$597, U$718: I360
U$25, U$69, U$238, U$242, U$359, U$363, U$480, U$484, U$601, U$605, U$722, U$726: VO0
U$26, U$235, U$356, U$477, U$598, U$719: VOUT0
U$27, U$108, U$255, U$376, U$497, U$618: RESET0
U$28, U$109, U$256, U$377, U$498, U$619: BOOT0
U$29, U$114, U$257, U$378, U$499, U$620: PWR0
U$30, U$129, U$258, U$379, U$500, U$621: STAT0
U$31, U$130, U$259, U$380, U$501, U$622: IO20
U$32, U$131, U$260, U$381, U$502, U$623: ORW0
U$33, U$132, U$261, U$382, U$503, U$624: OR0
U$34, U$133, U$262, U$383, U$504, U$625: GRW0
U$35, U$134, U$263, U$384, U$505, U$626: GR0
U$36, U$135, U$264, U$385, U$506, U$627: BLW0
U$37, U$136, U$265, U$386, U$507, U$628: BL0
U$38, U$145, U$266, U$387, U$508, U$629: BRW0
U$39, U$146, U$267, U$388, U$509, U$630: BR0
U$40, U$153, U$274, U$395, U$516, U$637: A#1
U$41, U$154, U$275, U$396, U$517, U$638: B#0
U$42, U$155, U$276, U$397, U$518, U$639: B#1
U$43, U$156, U$277, U$398, U$519, U$640: E#0
U$44, U$157, U$278, U$399, U$520, U$641: E#1
U$45, U$158, U$279, U$400, U$521, U$642: #RJ45_COLORS#0
U$46, U$159, U$280, U$401, U$522, U$643: #PWR#0
U$47, U$184, U$305, U$426, U$547, U$668: #3V3_#0
U$48, U$185, U$306, U$427, U$548, U$669: #SDA_#0
U$50, U$55, U$190, U$193, U$311, U$314, U$432, U$435, U$553, U$556, U$674, U$677: #LOAD_CELL#0
U$51, U$86, U$191, U$194, U$312, U$315, U$433, U$436, U$554, U$557, U$675, U$678: #GPIO_A#0
U$52, U$160, U$281, U$402, U$523, U$644: IO250
U$53, U$87, U$192, U$195, U$313, U$316, U$434, U$437, U$555, U$558, U$676, U$679: #GPIO_B#0
U$54, U$161, U$282, U$403, U$524, U$645: IO330
U$56, U$186, U$307, U$428, U$549, U$670: #SCL_#0
U$57, U$198, U$319, U$440, U$561, U$682: NC0
U$58, U$162, U$283, U$404, U$525, U$646: IO170
U$59, U$163, U$284, U$405, U$526, U$647: IO180
U$60, U$164, U$285, U$406, U$527, U$648: IO190
U$61, U$165, U$286, U$407, U$528, U$649: I340
U$62, U$166, U$287, U$408, U$529, U$650: I350
U$64, U$167, U$288, U$409, U$530, U$651: I390
U$65, U$168, U$289, U$410, U$531, U$652: #IO19#0
U$66, U$169, U$290, U$411, U$532, U$653: #IO18#0
U$68, U$240, U$361, U$482, U$603, U$724: #IO23#0
U$70, U$171, U$292, U$413, U$534, U$655: #NAU_INT#0
U$71, U$172, U$293, U$414, U$535, U$656: #MMC_INT#0
U$72, U$173, U$294, U$415, U$536, U$657: #ISM_INT2#0
U$73, U$174, U$295, U$416, U$537, U$658: #ISM_INT1#0
U$74, U$175, U$296, U$417, U$538, U$659: #ICM_INT#0
U$75, U$176, U$297, U$418, U$539, U$660: #IO#0
U$76, U$177, U$298, U$419, U$540, U$661: ##INT##0
U$77, U$178, U$299, U$420, U$541, U$662: #NOTES#0
U$78, U$179, U$300, U$421, U$542, U$663: IO230
U$81, U$187, U$308, U$429, U$550, U$671: #_SCL#1
U$82, U$121, U$125, U$201, U$205, U$209, U$322, U$326, U$330, U$443, U$447, U$451, U$564, U$568, U$572, U$685, U$689, U$693: OPEN#0
U$83, U$122, U$126, U$202, U$206, U$210, U$323, U$327, U$331, U$444, U$448, U$452, U$565, U$569, U$573, U$686, U$690, U$694: CLOSED#0
U$84, U$188, U$309, U$430, U$551, U$672: #_SDA#2
U$85, U$189, U$310, U$431, U$552, U$673: #_3V3#0
U$88, U$236, U$357, U$478, U$599, U$720: #GPS#0
U$89, U$237, U$358, U$479, U$600, U$721: GND3
U$94, U$100, U$104, U$138, U$213, U$221, U$228, U$231, U$334, U$342, U$349, U$352, U$455, U$463, U$470, U$473, U$576, U$584, U$591, U$594, U$697, U$705, U$712, U$715: X0
U$95, U$102, U$105, U$139, U$214, U$222, U$229, U$232, U$335, U$343, U$350, U$353, U$456, U$464, U$471, U$474, U$577, U$585, U$592, U$595, U$698, U$706, U$713, U$716: Y0
U$96, U$103, U$106, U$140, U$215, U$223, U$230, U$233, U$336, U$344, U$351, U$354, U$457, U$465, U$472, U$475, U$578, U$586, U$593, U$596, U$699, U$707, U$714, U$717: Z0
U$110, U$137, U$216, U$220, U$337, U$341, U$458, U$462, U$579, U$583, U$700, U$704: ICM0
U$111, U$217, U$338, U$459, U$580, U$701: ISM0
U$112, U$218, U$339, U$460, U$581, U$702: MMC0
U$113, U$219, U$340, U$461, U$582, U$703: IMU_AXES0
U$117, U$199, U$320, U$441, U$562, U$683: #5V_IN_#0
U$118, U$200, U$321, U$442, U$563, U$684: #_5V_IN#0
U$119, U$203, U$324, U$445, U$566, U$687: 0X770
U$120, U$204, U$325, U$446, U$567, U$688: 0X760
U$123, U$211, U$332, U$453, U$574, U$695: 0X6A0
U$124, U$212, U$333, U$454, U$575, U$696: 0X6B0
U$127, U$207, U$328, U$449, U$570, U$691: 0X690
U$128, U$208, U$329, U$450, U$571, U$692: 0X680
U$141, U$142, U$224, U$225, U$345, U$346, U$466, U$467, U$587, U$588, U$708, U$709: MAG0
U$143, U$144, U$226, U$227, U$347, U$348, U$468, U$469, U$589, U$590, U$710, U$711: A#G0

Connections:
1.8V: C10.1, C11.1, C12.1, Q2.1, Q3.1, R14.2, R15.2, R16.2, TP1.1, U6.8, U6.13, U6.22, U7.5
1.8V1: C33.1, C34.1, C35.1, Q13.1, Q14.1, R44.2, R45.2, R46.2, TP2.1, U16.8, U16.13, U16.22, U17.5
1.8V2: C57.1, C58.1, C59.1, Q24.1, Q25.1, R75.2, R76.2, R77.2, TP3.1, U27.8, U27.13, U27.22, U28.5
1.8V3: C81.1, C82.1, C83.1, Q35.1, Q36.1, R106.2, R107.2, R108.2, TP4.1, U38.8, U38.13, U38.22, U39.5
1.8V4: C105.1, C106.1, C107.1, Q46.1, Q47.1, R137.2, R138.2, R139.2, TP5.1, U49.8, U49.13, U49.22, U50.5
1.8V5: C129.1, C130.1, C131.1, Q57.1, Q58.1, R168.2, R169.2, R170.2, TP6.1, U60.8, U60.13, U60.22, U61.5
3.3V: C2.2, C3.1, C24.1, D2.A, I2C.2, J3.2, J7.7, J8.3, J9.7, L1.P$2, Q7.2, Q10.2, R5.2, R26.2, R27.2, R31.2, U1.2
3.3V1: C26.1, C27.2, C47.1, D8.A, I2C1.2, J15.2, J19.7, J20.7, J22.3, L2.P$2, Q18.2, Q21.2, R36.2, R57.2, R58.2, R62.2, U4.2
3.3V2: C50.1, C51.2, C71.1, D14.A, I2C2.2, J27.2, J31.7, J32.7, J34.3, L3.P$2, Q29.2, Q32.2, R67.2, R88.2, R89.2, R93.2, U23.2
3.3V3: C74.1, C75.2, C95.1, D20.A, I2C3.2, J39.2, J43.7, J44.7, J46.3, L4.P$2, Q40.2, Q43.2, R98.2, R119.2, R120.2, R124.2, U34.2
3.3V4: C98.1, C99.2, C119.1, D26.A, I2C4.2, J51.2, J55.7, J56.7, J58.3, L5.P$2, Q51.2, Q54.2, R129.2, R150.2, R151.2, R155.2, U45.2
3.3V5: C122.1, C123.2, C143.1, D32.A, I2C5.2, J63.2, J67.7, J68.7, J70.3, L6.P$2, Q62.2, Q65.2, R160.2, R181.2, R182.2, R186.2, U56.2
3V3_EN: R4.2, U2.1
3V3_EN1: R35.2, U13.1
3V3_EN2: R66.2, U24.1
3V3_EN3: R97.2, U35.1
3V3_EN4: R128.2, U46.1
3V3_EN5: R159.2, U57.1
5V: C4.1, D1.A, D5.C, J11.1, Q1.1, R3.2, R7.2, U3.4
5V1: C28.1, D7.A, D11.C, J23.1, Q12.1, R34.2, R38.2, U14.4
5V2: C52.1, D13.A, D17.C, J35.1, Q23.1, R65.2, R69.2, U25.4
5V3: C76.1, D19.A, D23.C, J47.1, Q34.1, R96.2, R100.2, U36.4
5V4: C100.1, D25.A, D29.C, J59.1, Q45.1, R127.2, R131.2, U47.4
5V5: C124.1, D31.A, D35.C, J71.1, Q56.1, R158.2, R162.2, U58.4
DTR: Q6.1, R20.1, U8.13
DTR1: Q16.1, R53.1, U18.13
DTR2: Q27.1, R84.1, U29.13
DTR3: Q38.1, R115.1, U40.13
DTR4: Q49.1, R146.1, U51.13
DTR5: Q60.1, R177.1, U62.13
ESP_EN: Q6.3, R26.1, RESET.3, RESET.4, U1.3
ESP_EN1: Q16.3, R57.1, RESET1.3, RESET1.4, U4.3
ESP_EN2: Q27.3, R88.1, RESET2.3, RESET2.4, U23.3
ESP_EN3: Q38.3, R119.1, RESET3.3, RESET3.4, U34.3
ESP_EN4: Q49.3, R150.1, RESET4.3, RESET4.4, U45.3
ESP_EN5: Q60.3, R181.1, RESET5.3, RESET5.4, U56.3
ESP_I1: J19.3, U4.6
ESP_I2: J19.1, U4.7
ESP_I3: J19.6, U4.5
ESP_I4: J31.3, U23.6
ESP_I5: J31.1, U23.7
ESP_I6: J31.6, U23.5
ESP_I7: J43.3, U34.6
ESP_I8: J43.1, U34.7
ESP_I9: J43.6, U34.5
ESP_I10: J55.3, U45.6
ESP_I11: J55.1, U45.7
ESP_I12: J55.6, U45.5
ESP_I13: J67.3, U56.6
ESP_I14: J67.1, U56.7
ESP_I15: J67.6, U56.5
ESP_I34: J7.3, U1.6
ESP_I35: J7.1, U1.7
ESP_I36/GPS_TX: J12.1, U1.4
ESP_I36/GPS_TX1: J24.1, U4.4
ESP_I36/GPS_TX2: J36.1, U23.4
ESP_I36/GPS_TX3: J48.1, U34.4
ESP_I36/GPS_TX4: J60.1, U45.4
ESP_I36/GPS_TX5: J72.1, U56.4
ESP_I39: J7.6, U1.5
ESP_IO0/BOOT: BOOT.3, BOOT.4, Q6.6, U1.25
ESP_IO0/BOOT1: BOOT1.3, BOOT1.4, Q16.6, U4.25
ESP_IO0/BOOT2: BOOT2.3, BOOT2.4, Q27.6, U23.25
ESP_IO0/BOOT3: BOOT3.3, BOOT3.4, Q38.6, U34.25
ESP_IO0/BOOT4: BOOT4.3, BOOT4.4, Q49.6, U45.25
ESP_IO0/BOOT5: BOOT5.3, BOOT5.4, Q60.6, U56.25
ESP_IO1: ICM_INT1.1, ISM_INT3.1, J20.1, U4.28
ESP_IO1/ESP_TX: U1.35, U8.3
ESP_IO1/ESP_TX1: U4.35, U18.3
ESP_IO1/ESP_TX2: U23.35, U29.3
ESP_IO1/ESP_TX3: U34.35, U40.3
ESP_IO1/ESP_TX4: U45.35, U51.3
ESP_IO1/ESP_TX5: U56.35, U62.3
ESP_IO2: ISM_INT4.1, J20.2, U4.30
ESP_IO2/STAT: D4.A, U1.24
ESP_IO2/STAT1: D10.A, U4.24
ESP_IO2/STAT2: D16.A, U23.24
ESP_IO2/STAT3: D22.A, U34.24
ESP_IO2/STAT4: D28.A, U45.24
ESP_IO2/STAT5: D34.A, U56.24
ESP_IO3: J20.3, MMC_INT1.1, U4.31
ESP_IO3/ESP_RX: U1.34, U8.2
ESP_IO3/ESP_RX1: U4.34, U18.2
ESP_IO3/ESP_RX2: U23.34, U29.2
ESP_IO3/ESP_RX3: U34.34, U40.2
ESP_IO3/ESP_RX4: U45.34, U51.2
ESP_IO3/ESP_RX5: U56.34, U62.2
ESP_IO4: J20.4, NAU_INT1.1, U4.37
ESP_IO4/INT_COM: ICM_INT.3, ISM_INT1.3, ISM_INT2.3, MMC_INT.3, NAU_INT.3, R28.1, U1.26
ESP_IO4/INT_COM1: ICM_INT1.3, ISM_INT3.3, ISM_INT4.3, MMC_INT1.3, NAU_INT1.3, R61.1, U4.26
ESP_IO4/INT_COM2: ICM_INT2.3, ISM_INT5.3, ISM_INT6.3, MMC_INT2.3, NAU_INT2.3, R92.1, U23.26
ESP_IO4/INT_COM3: ICM_INT3.3, ISM_INT7.3, ISM_INT8.3, MMC_INT3.3, NAU_INT3.3, R123.1, U34.26
ESP_IO4/INT_COM4: ICM_INT4.3, ISM_INT9.3, ISM_INT10.3, MMC_INT4.3, NAU_INT4.3, R154.1, U45.26
ESP_IO4/INT_COM5: ICM_INT5.3, ISM_INT11.3, ISM_INT12.3, MMC_INT5.3, NAU_INT5.3, R185.1, U56.26
ESP_IO5: J19.2, U4.10
ESP_IO5/!RFM_RST!: U1.29, U11.!RESET
ESP_IO5/!RFM_RST!1: U4.29, U21.!RESET
ESP_IO5/!RFM_RST!2: U23.29, U32.!RESET
ESP_IO5/!RFM_RST!3: U34.29, U43.!RESET
ESP_IO5/!RFM_RST!4: U45.29, U54.!RESET
ESP_IO5/!RFM_RST!5: U56.29, U65.!RESET
ESP_IO6: J19.4, U4.9
ESP_IO7: ICM_INT2.1, ISM_INT5.1, J32.1, U23.28
ESP_IO8: ISM_INT6.1, J32.2, U23.30
ESP_IO9: J32.3, MMC_INT2.1, U23.31
ESP_IO10: J32.4, NAU_INT2.1, U23.37
ESP_IO11: J31.2, U23.10
ESP_IO12: J31.4, U23.9
ESP_IO12/POCI: U1.14, U11.SDO
ESP_IO12/POCI1: U4.14, U21.SDO
ESP_IO12/POCI2: U23.14, U32.SDO
ESP_IO12/POCI3: U34.14, U43.SDO
ESP_IO12/POCI4: U45.14, U54.SDO
ESP_IO12/POCI5: U56.14, U65.SDO
ESP_IO13: ICM_INT3.1, ISM_INT7.1, J44.1, U34.28
ESP_IO13/PICO: U1.16, U11.SDI
ESP_IO13/PICO1: U4.16, U21.SDI
ESP_IO13/PICO2: U23.16, U32.SDI
ESP_IO13/PICO3: U34.16, U43.SDI
ESP_IO13/PICO4: U45.16, U54.SDI
ESP_IO13/PICO5: U56.16, U65.SDI
ESP_IO14: ISM_INT8.1, J44.2, U34.30
ESP_IO14/SCK: U1.13, U11.SCK
ESP_IO14/SCK1: U4.13, U21.SCK
ESP_IO14/SCK2: U23.13, U32.SCK
ESP_IO14/SCK3: U34.13, U43.SCK
ESP_IO14/SCK4: U45.13, U54.SCK
ESP_IO14/SCK5: U56.13, U65.SCK
ESP_IO15: J44.3, MMC_INT3.1, U34.31
ESP_IO15/!RFM_CS!: U1.23, U11.NSS
ESP_IO15/!RFM_CS!1: U4.23, U21.NSS
ESP_IO15/!RFM_CS!2: U23.23, U32.NSS
ESP_IO15/!RFM_CS!3: U34.23, U43.NSS
ESP_IO15/!RFM_CS!4: U45.23, U54.NSS
ESP_IO15/!RFM_CS!5: U56.23, U65.NSS
ESP_IO16: J44.4, NAU_INT3.1, U34.37
ESP_IO16/!VOUT_EN!: Q7.1, R27.1, U1.27
ESP_IO16/!VOUT_EN!1: Q18.1, R58.1, U4.27
ESP_IO16/!VOUT_EN!2: Q29.1, R89.1, U23.27
ESP_IO16/!VOUT_EN!3: Q40.1, R120.1, U34.27
ESP_IO16/!VOUT_EN!4: Q51.1, R151.1, U45.27
ESP_IO16/!VOUT_EN!5: Q62.1, R182.1, U56.27
ESP_IO17: ICM_INT.1, ISM_INT1.1, J9.1, U1.28
ESP_IO18: ISM_INT2.1, J9.2, U1.30
ESP_IO19: J9.3, MMC_INT.1, U1.31
ESP_IO20: J43.2, U34.10
ESP_IO21: J43.4, U34.9
ESP_IO21/SDA: J3.3, J8.2, Q8.3, R12.1, U1.33
ESP_IO21/SDA1: J15.3, J22.2, Q19.3, R42.1, U4.33
ESP_IO21/SDA2: J27.3, J34.2, Q30.3, R73.1, U23.33
ESP_IO21/SDA3: J39.3, J46.2, Q41.3, R104.1, U34.33
ESP_IO21/SDA4: J51.3, J58.2, Q52.3, R135.1, U45.33
ESP_IO21/SDA5: J63.3, J70.2, Q63.3, R166.1, U56.33
ESP_IO22: ICM_INT4.1, ISM_INT9.1, J56.1, U45.28
ESP_IO22/SCL: J3.4, J8.1, Q9.3, R11.1, U1.36
ESP_IO22/SCL1: J15.4, J22.1, Q20.3, R41.1, U4.36
ESP_IO22/SCL2: J27.4, J34.1, Q31.3, R72.1, U23.36
ESP_IO22/SCL3: J39.4, J46.1, Q42.3, R103.1, U34.36
ESP_IO22/SCL4: J51.4, J58.1, Q53.3, R134.1, U45.36
ESP_IO22/SCL5: J63.4, J70.1, Q64.3, R165.1, U56.36
ESP_IO23: J9.4, NAU_INT.1, U1.37
ESP_IO24: ISM_INT10.1, J56.2, U45.30
ESP_IO25: J7.2, U1.10
ESP_IO26: J56.3, MMC_INT4.1, U45.31
ESP_IO26/RFM_IO1: U1.11, U11.DIO1
ESP_IO26/RFM_IO2: U4.11, U21.DIO1
ESP_IO26/RFM_IO3: U23.11, U32.DIO1
ESP_IO26/RFM_IO4: U34.11, U43.DIO1
ESP_IO26/RFM_IO5: U45.11, U54.DIO1
ESP_IO26/RFM_IO6: U56.11, U65.DIO1
ESP_IO27: J56.4, NAU_INT4.1, U45.37
ESP_IO27/RFM_IO0: U1.12, U11.DIO0
ESP_IO27/RFM_IO1: U4.12, U21.DIO0
ESP_IO27/RFM_IO2: U23.12, U32.DIO0
ESP_IO27/RFM_IO3: U34.12, U43.DIO0
ESP_IO27/RFM_IO4: U45.12, U54.DIO0
ESP_IO27/RFM_IO5: U56.12, U65.DIO0
ESP_IO28: J55.2, U45.10
ESP_IO29: J55.4, U45.9
ESP_IO30: ICM_INT5.1, ISM_INT11.1, J68.1, U56.28
ESP_IO31: ISM_INT12.1, J68.2, U56.30
ESP_IO32: J68.3, MMC_INT5.1, U56.31
ESP_IO32/V_BATT_1: R55.2, R56.1, U4.8
ESP_IO32/V_BATT_2: R9.2, R25.1, U1.8
ESP_IO32/V_BATT_3: R86.2, R87.1, U23.8
ESP_IO32/V_BATT_4: R117.2, R118.1, U34.8
ESP_IO32/V_BATT_5: R148.2, R149.1, U45.8
ESP_IO32/V_BATT_6: R179.2, R180.1, U56.8
ESP_IO33: J7.4, U1.9
ESP_IO34: J68.4, NAU_INT5.1, U56.37
ESP_IO35: J67.2, U56.10
ESP_IO36: J67.4, U56.9
GND: BME_ADR.1, BOOT.1, BOOT.2, C1.2, C3.2, C4.2, C5.2, C6.2, C7.2, C8.2, C9.2, C10.2, C11.2, C12.2, C13.2, C14.2, C15.2, C16.2, C17.2, C18.2, C19.2, C22.2, C23.2, C24.2, ICM_ADR.1, ISM_ADR.1, J1.GND, J1.GND2, J2.1, J3.1, J4.1, J4.2, J5.3, J5.8, J6.2, J7.8, J8.4, J9.8, J10.1, J11.2, J12.2, PWR.1, Q4.2, Q11.2, R1.1, R2.1, R3.1, R6.1, R8.1, R9.1, R18.1, R24.1, R28.2, RESET.1, RESET.2, SHLD.1, U1.1, U1.15, U1.38, U1.GND, U1.GNDT1, U1.GNDT2, U1.GNDT3, U1.GNDT4, U1.GNDT5, U1.GNDT6, U1.GNDT7, U1.GNDT8, U2.2, U3.2, U5.1, U5.7, U6.18, U6.20, U7.2, U8.1, U9.P6, U9.P7, U10.9, U10.11, U11.GND@1, U11.GND@2, U11.GND@3, U12.7, U12.8, U12.9
GND1: BME_ADR1.1, BOOT1.1, BOOT1.2, C25.2, C26.2, C28.2, C29.2, C30.2, C31.2, C32.2, C33.2, C34.2, C35.2, C36.2, C37.2, C38.2, C39.2, C40.2, C41.2, C42.2, C45.2, C46.2, C47.2, C48.2, ICM_ADR1.1, ISM_ADR1.1, J13.GND, J13.GND2, J14.1, J15.1, J16.1, J16.2, J17.2, J18.3, J18.8, J19.8, J20.8, J21.1, J22.4, J23.2, J24.2, PWR1.1, Q15.2, Q22.2, R32.1, R33.1, R34.1, R37.1, R39.1, R48.1, R54.1, R55.1, R61.2, RESET1.1, RESET1.2, SHLD1.1, U4.1, U4.15, U4.38, U4.GND, U4.GNDT1, U4.GNDT2, U4.GNDT3, U4.GNDT4, U4.GNDT5, U4.GNDT6, U4.GNDT7, U4.GNDT8, U13.2, U14.2, U15.1, U15.7, U16.18, U16.20, U17.2, U18.1, U19.P6, U19.P7, U20.9, U20.11, U21.GND@1, U21.GND@2, U21.GND@3, U22.7, U22.8, U22.9
GND4: BME_ADR2.1, BOOT2.1, BOOT2.2, C49.2, C50.2, C52.2, C53.2, C54.2, C55.2, C56.2, C57.2, C58.2, C59.2, C60.2, C61.2, C62.2, C63.2, C64.2, C65.2, C66.2, C69.2, C70.2, C71.2, C72.2, ICM_ADR2.1, ISM_ADR2.1, J25.GND, J25.GND2, J26.1, J27.1, J28.1, J28.2, J29.2, J30.3, J30.8, J31.8, J32.8, J33.1, J34.4, J35.2, J36.2, PWR2.1, Q26.2, Q33.2, R63.1, R64.1, R65.1, R68.1, R70.1, R79.1, R85.1, R86.1, R92.2, RESET2.1, RESET2.2, SHLD2.1, U23.1, U23.15, U23.38, U23.GND, U23.GNDT1, U23.GNDT2, U23.GNDT3, U23.GNDT4, U23.GNDT5, U23.GNDT6, U23.GNDT7, U23.GNDT8, U24.2, U25.2, U26.1, U26.7, U27.18, U27.20, U28.2, U29.1, U30.P6, U30.P7, U31.9, U31.11, U32.GND@1, U32.GND@2, U32.GND@3, U33.7, U33.8, U33.9
GND6: BME_ADR3.1, BOOT3.1, BOOT3.2, C73.2, C74.2, C76.2, C77.2, C78.2, C79.2, C80.2, C81.2, C82.2, C83.2, C84.2, C85.2, C86.2, C87.2, C88.2, C89.2, C90.2, C93.2, C94.2, C95.2, C96.2, ICM_ADR3.1, ISM_ADR3.1, J37.GND, J37.GND2, J38.1, J39.1, J40.1, J40.2, J41.2, J42.3, J42.8, J43.8, J44.8, J45.1, J46.4, J47.2, J48.2, PWR3.1, Q37.2, Q44.2, R94.1, R95.1, R96.1, R99.1, R101.1, R110.1, R116.1, R117.1, R123.2, RESET3.1, RESET3.2, SHLD3.1, U34.1, U34.15, U34.38, U34.GND, U34.GNDT1, U34.GNDT2, U34.GNDT3, U34.GNDT4, U34.GNDT5, U34.GNDT6, U34.GNDT7, U34.GNDT8, U35.2, U36.2, U37.1, U37.7, U38.18, U38.20, U39.2, U40.1, U41.P6, U41.P7, U42.9, U42.11, U43.GND@1, U43.GND@2, U43.GND@3, U44.7, U44.8, U44.9
GND8: BME_ADR4.1, BOOT4.1, BOOT4.2, C97.2, C98.2, C100.2, C101.2, C102.2, C103.2, C104.2, C105.2, C106.2, C107.2, C108.2, C109.2, C110.2, C111.2, C112.2, C113.2, C114.2, C117.2, C118.2, C119.2, C120.2, ICM_ADR4.1, ISM_ADR4.1, J49.GND, J49.GND2, J50.1, J51.1, J52.1, J52.2, J53.2, J54.3, J54.8, J55.8, J56.8, J57.1, J58.4, J59.2, J60.2, PWR4.1, Q48.2, Q55.2, R125.1, R126.1, R127.1, R130.1, R132.1, R141.1, R147.1, R148.1, R154.2, RESET4.1, RESET4.2, SHLD4.1, U45.1, U45.15, U45.38, U45.GND, U45.GNDT1, U45.GNDT2, U45.GNDT3, U45.GNDT4, U45.GNDT5, U45.GNDT6, U45.GNDT7, U45.GNDT8, U46.2, U47.2, U48.1, U48.7, U49.18, U49.20, U50.2, U51.1, U52.P6, U52.P7, U53.9, U53.11, U54.GND@1, U54.GND@2, U54.GND@3, U55.7, U55.8, U55.9
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

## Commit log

2022-12-15 Add initial schematic and board layout
    [USDA_Project.brd, USDA_Project.sch]
2022-12-15 Finish 90% of initial design
    Rename Eagle files to match project name
    Clean up schematic arrangement
    Finish 90% of routing (ESP32 connections will be determined later)
    Add Buzzard labels
    [SparkFun_USDA_Watershed_Monitor.brd, SparkFun_USDA_Watershed_Monitor.sch]
2022-12-21 Finish initial design
    Increase board height from 2 to 2.5 inches
    Move LoRa module up, and antenna to top side of board
    Replace load cell spring terminal and GPIO header with RJ45 jacks
    Add second Qwiic connector to left side of board
    Remove fuel gauge
    Remove CHG_I jumper, and set charge current to 500mA only
    Reroute I2C lines to make room for GPIO going to bottom of the board
    Connect and route GPIO lines to bottom RJ45 connectors
    Adjust/add buzzard labels
    Add region on back silk for board notes
    Season with GND vias
    [SparkFun_USDA_Watershed_Monitor.brd, SparkFun_USDA_Watershed_Monitor.sch]
2023-01-03 Cleanup design
    Connect interrupt net to IO4
    Connect V_BATT to IO32 pin through voltage divider to measure battery voltage
    Increase 3V3 trace width to 25 mils on low half of board
    [SparkFun_USDA_Watershed_Monitor.brd, SparkFun_USDA_Watershed_Monitor.sch]
2023-01-10 Replace center RJ45 with header pins
    Fully populate other RJ45's with GPIO pins, leaving 2 free GPIO pins going to header pins
    [SparkFun_USDA_Watershed_Monitor.brd, SparkFun_USDA_Watershed_Monitor.sch]
2023-01-10 Clean up connectors in schematic
    [SparkFun_USDA_Watershed_Monitor.sch]
2023-01-10 Add 5V header
    Add 5V header for power injection
    Rename V_USB net to 5V
    Add diode to USB input to protect against 5V contention
    Header took place of I2C pullups, so those got moved to other side of Qwiic connector
    Add units to measures
    [SparkFun_USDA_Watershed_Monitor.brd, SparkFun_USDA_Watershed_Monitor.sch]
2023-01-12 Schematic review updates
    Add note about ICM-20948 going EOL
    Add I2C addresses of all sensors
    Add max input voltage to regulators
    Add value to 3V3 regulator
    Add boot table to auto reset
    Change power LED resistor to 1k
    Move load cell connector with other connectors
    Remove bar from interrupt net names
    [SparkFun_USDA_Watershed_Monitor.brd, SparkFun_USDA_Watershed_Monitor.sch]
2023-01-13 Design review updates
    Replace "VUSB" buzzard label with "5V"
    Add test point for 1.8V net
    Nudge C22 to the left
    Add selective solder paths
    Move u.FL connector away from board edge
    Nudge GPIO lines under load cell connector to the left
    Rename GPIO nets that aren't broken out to connectors with more helpful names
    Fix CH340 capacitors (100nF on VCC only, add 10nF to V3 and disconnect from 3.3V net)
    Move USB connector to not overhang edge (better for panelization)
    Move CC resistors and VUSB diode next to battery PTH pads
    [SparkFun_USDA_Watershed_Monitor.brd, SparkFun_USDA_Watershed_Monitor.sch]
2023-01-13 Move load cell connector to bottom edge
    Will help a lot with panelization
    Moved left GPIO RJ45 connector to bottom middle, and redid connections for easier routing
    [SparkFun_USDA_Watershed_Monitor.brd, SparkFun_USDA_Watershed_Monitor.sch]
2023-01-13 Connect RFM95W pins
    Somebody forgot to connect them...
    Connect ESP32's IO5 and IO15 (both internally pulled high) to RFM's RESET and CS respectively
    Connect ESP32's IO26 and IO27 to RFM's IO1 and IO0 respectively (IO2 not needed for LoRa)
    ESP32's IO15, IO26, and IO27 are no longer broken out to RJ45 or headers
    Add pullup resistor to ESP_EN
    [SparkFun_USDA_Watershed_Monitor.brd, SparkFun_USDA_Watershed_Monitor.sch]
2023-01-13 Design review updates
    Remove 3V3_EN and ICM's FSYNC nets (won't be used)
    Add diode to NAU_INT (chip doesn't do open-drain)
    Clarify interrupts needing to be open-drain, active high
    Fix ICM interrupt level shifter output to be high-Z when input is low (or high-Z), and drive high when input is high
    Add version number to copper
    Add silk labels to RJ45s, and dashed lines connecting pinout to color code
    Add IMU axis albels to silk
    [SparkFun_USDA_Watershed_Monitor.brd, SparkFun_USDA_Watershed_Monitor.sch]
2023-01-13 Checklist updates
    Add measures or PTH pads
    Copy SFE logo and board name silk on back side
    [SparkFun_USDA_Watershed_Monitor.brd]
2023-01-13 Add MMC I2C address to schematic
    [SparkFun_USDA_Watershed_Monitor.brd, SparkFun_USDA_Watershed_Monitor.sch]
2023-01-13 Fix ISM and MMC axis silk labels
    They were flipped, just swapped the names
    [SparkFun_USDA_Watershed_Monitor.brd]
2023-01-17 Add VOUT net for GPIO A, left Qwiic, and load cell
    Controlled by a P-channel MOSFET, had to steal GPIO16
    Also changed "5V" label to "5V IN"
    [SparkFun_USDA_Watershed_Monitor.brd, SparkFun_USDA_Watershed_Monitor.sch]
2023-01-17 Add proto production files
    [SparkFun_USDA_Watershed_Monitor-Panel.GBL, SparkFun_USDA_Watershed_Monitor-Panel.GBO, SparkFun_USDA_Watershed_Monitor-Panel.GBP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]
2023-01-17 Update DNP component values and PROD_ID's
    [SparkFun_USDA_Watershed_Monitor.brd, SparkFun_USDA_Watershed_Monitor.sch]
2023-03-22 Add 3-pin JST connector for GPS
    [SparkFun_USDA_Watershed_Monitor.brd, SparkFun_USDA_Watershed_Monitor.sch]
2023-03-22 Connect all onboard sensors and LoRa to VOUT
    Helps achieve lower power
    [SparkFun_USDA_Watershed_Monitor.brd, SparkFun_USDA_Watershed_Monitor.sch]
2023-03-23 Add level shifter circuits for I2C sensors on VOUT
    Sensors can get back powered through SDA and SCL pullups
    Added MOSFET level shifter circuits to create new SDA/SCL_OUT nets with pullups to VOUT
    Updated routing accordingly
    [SparkFun_USDA_Watershed_Monitor.brd, SparkFun_USDA_Watershed_Monitor.sch]
2023-03-23 Design review updates
    Bump version number to v10
    Change BME_ADR from NO to NC
    Add I2C addresses to silk
    Remove hot warning from silk
    Add better pin 1 indicator for BBME680
    Add 100k pulldown on ESP_INT_COM net
    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
    [SparkFun_USDA_Watershed_Monitor.brd, SparkFun_USDA_Watershed_Monitor.sch]
2023-03-27 Design review updates
    Add power control to CH340 (required some components in top right corner to be rearranged)
    Nudge fiducials and OSHW logo
    Update GPS connector silk
    Update RJ45 connector "A" pinout silk to have "VO" instead of "3V3"
    Fix STAT LED measure
    [SparkFun_USDA_Watershed_Monitor.brd, SparkFun_USDA_Watershed_Monitor.sch]
2023-03-27 Rearrange CH340 power control components
    Gives more space around D5, its pads were close to other GND pads
    [SparkFun_USDA_Watershed_Monitor.brd]
2023-03-27 Fix battery polarity silk
    [SparkFun_USDA_Watershed_Monitor.brd]
2023-03-27 Flip and nudge CH340 power control components
    Again...
    Gives more clearance between components and pads
    [SparkFun_USDA_Watershed_Monitor.brd]
2023-03-27 Reorient CAP jumper label
    [SparkFun_USDA_Watershed_Monitor.brd]
2023-03-28 Update power LED
    Change to new SKU
    Set as DNP
    [SparkFun_USDA_Watershed_Monitor.brd, SparkFun_USDA_Watershed_Monitor.sch]
2023-03-28 Add 3V3 and VOUT to both RJ45 GPIO connectors
    [SparkFun_USDA_Watershed_Monitor.brd, SparkFun_USDA_Watershed_Monitor.sch]
2023-03-28 Update GPIO net names
    Include both the ESP GPIO number, and the destination
    Required schematic to be nudged around in a couple places
    [SparkFun_USDA_Watershed_Monitor.brd, SparkFun_USDA_Watershed_Monitor.sch]
2023-03-28 Reorder alternative interrupt pins
    ESP16 was shared between an alternative interrupt, and the power control
    [SparkFun_USDA_Watershed_Monitor.brd, SparkFun_USDA_Watershed_Monitor.sch]
2023-03-28 Change CH340 power control to be based on VUSB instead of 5V net
    [SparkFun_USDA_Watershed_Monitor.brd, SparkFun_USDA_Watershed_Monitor.sch]
2023-03-28 Update RJ45 connector silk
    [SparkFun_USDA_Watershed_Monitor.brd]
2023-03-29 Fix load cell B+/- pinout
    Update to match silkscreen
    [SparkFun_USDA_Watershed_Monitor.brd, SparkFun_USDA_Watershed_Monitor.sch]
2023-03-29 Add note to schematic about CH340 power
    [SparkFun_USDA_Watershed_Monitor.sch]
2023-03-29 Add note about VOUT to schematic
    Add note instructing how to enable VOUT
    Rename net to !VOUT_EN!
    [SparkFun_USDA_Watershed_Monitor.brd, SparkFun_USDA_Watershed_Monitor.sch]
2023-04-03 Checklist updates
    Add ordering instructions
    Minor silk tweaks
    [SparkFun_USDA_Watershed_Monitor.brd]
2023-04-03 Add v10 production files
    [SparkFun_USDA_Watershed_Monitor-Panel.brd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]
2023-05-01 Change DIO-14072 for DIO-11623
    [SparkFun_USDA_Watershed_Monitor-Panel.brd, SparkFun_USDA_Watershed_Monitor.brd, SparkFun_USDA_Watershed_Monitor.sch]
2023-09-22 v11 updates
    Bump version number to v11
    Remove USDA from silkscreen
    Repanelize
    [SparkFun_USDA_Watershed_Monitor-Panel.brd, SparkFun_USDA_Watershed_Monitor.brd, SparkFun_USDA_Watershed_Monitor.sch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]
2023-09-22 Update file names
    Remove USDA references
    [SparkFun_USDA_Watershed_Monitor.brd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]

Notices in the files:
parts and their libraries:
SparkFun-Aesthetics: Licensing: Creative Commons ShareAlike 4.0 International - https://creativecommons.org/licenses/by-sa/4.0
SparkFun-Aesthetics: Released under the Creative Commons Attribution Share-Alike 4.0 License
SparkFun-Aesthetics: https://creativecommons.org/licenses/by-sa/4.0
